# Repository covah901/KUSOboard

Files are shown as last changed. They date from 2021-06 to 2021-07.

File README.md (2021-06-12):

# KUSOboard
KUSOboard is a Longan Nano based keyboard using KarlK90's branch of QMK 
All info on Karl's branch and YAEMK can be found here: https://karlk90.github.io/yaemk-split-kb/

Regarding the naming of the files, I had started out meaning to make an Atreus size board, but decided against it shortly after starting the project. 
It was reduced to something more like a Reviung39. 

album: https://imgur.com/a/PWmJwKW

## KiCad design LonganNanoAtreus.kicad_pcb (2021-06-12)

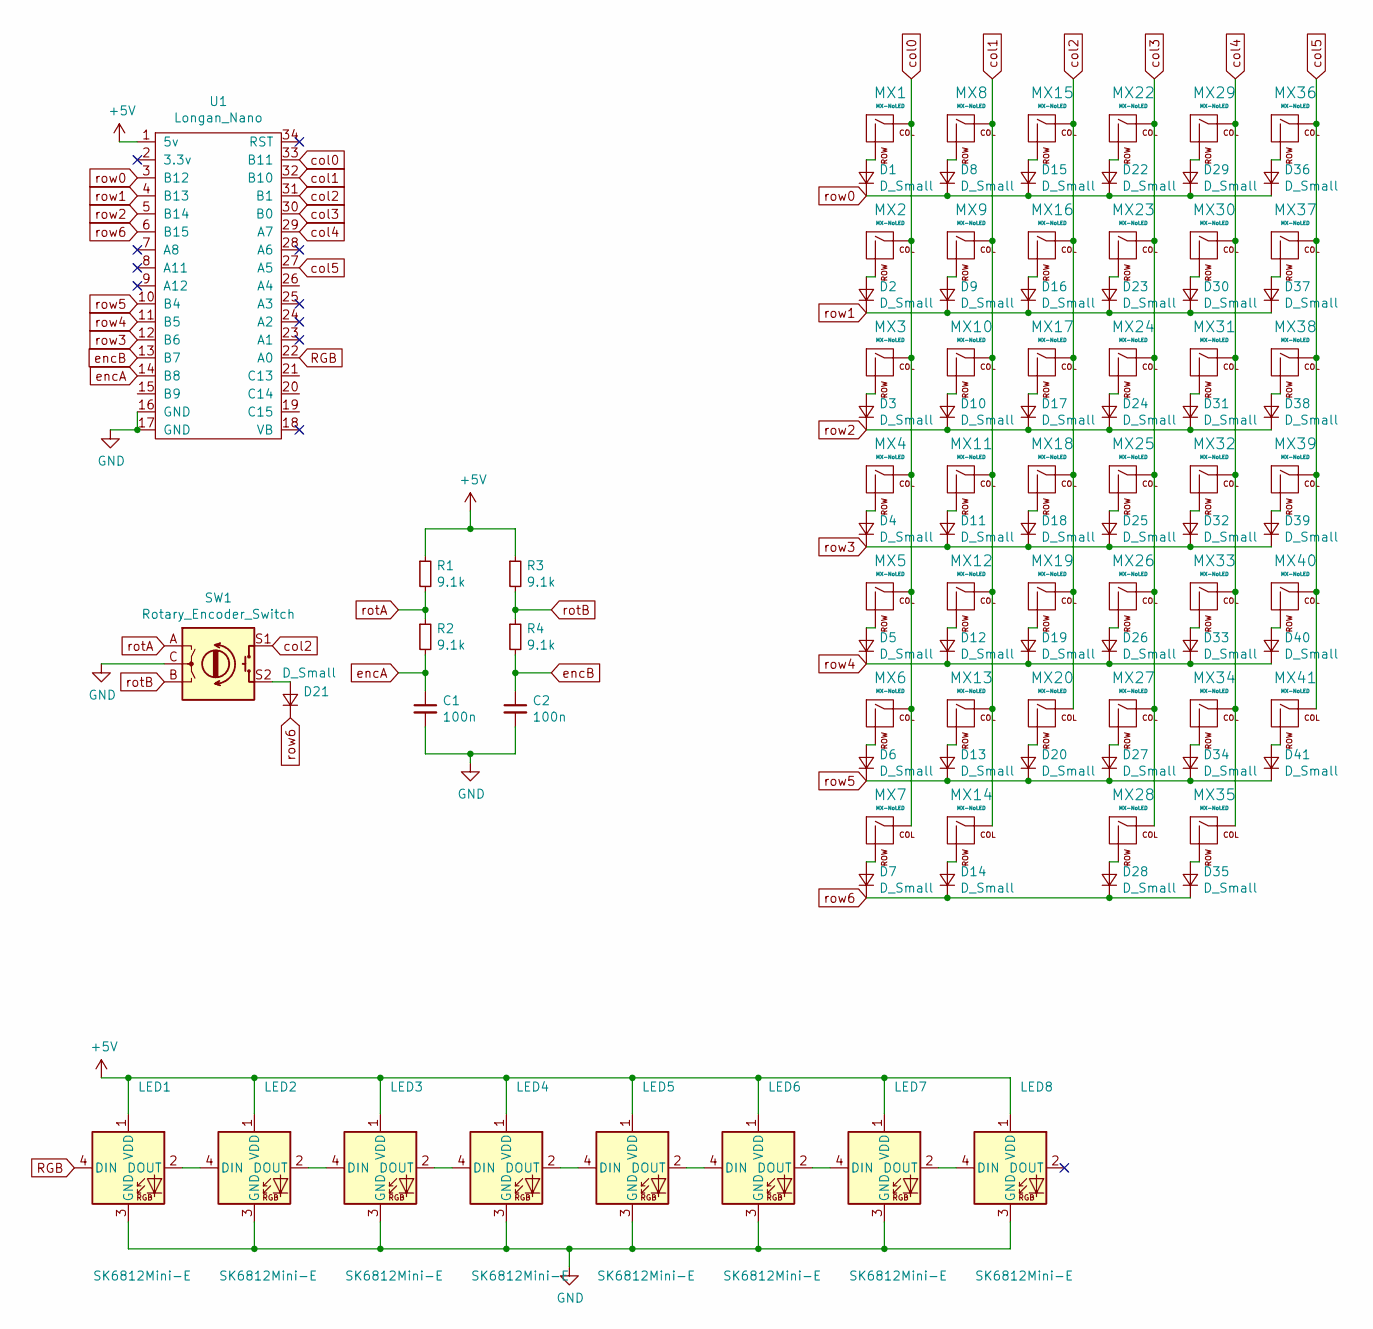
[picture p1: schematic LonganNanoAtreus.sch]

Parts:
C1, C2: 100n; C_0805_2012Metric_Pad1.15x1.40mm_HandSolder
D1, D2, D3, D4, D5, D6, D7, D8, D9, D10, D11, D12, D13, D14, D15, D16, D17, D18, D19, D20, D21, D22, D23, D24, D25, D26, D27, D28, D29, D30, D31, D32, D33, D34, D35, D36, D37, D38, D39, D40, D41: D_Small; D_SOD-123F
LED1, LED2, LED3, LED4, LED5, LED6, LED7, LED8: SK6812Mini-E; SK6812-MINI-E
MX1, MX2, MX3, MX4, MX5, MX6, MX7, MX8, MX9, MX10, MX11, MX12, MX13, MX14, MX15, MX16, MX17, MX18, MX19, MX20, MX22, MX23, MX24, MX25, MX26, MX27, MX28, MX29, MX30, MX31, MX32, MX33, MX34, MX35, MX36, MX37, MX38, MX39, MX40, MX41: MX-NoLED; MXOnly-1U-NoLED
R1, R2, R3, R4: 9.1k; R_0805_2012Metric_Pad1.15x1.40mm_HandSolder
SW1: Rotary_Encoder_Switch; EVQWGD001
U1: Longan_Nano

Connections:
+5V: LED1.1 (VDD), LED2.1 (VDD), LED3.1 (VDD), LED4.1 (VDD), LED5.1 (VDD), LED6.1 (VDD), LED7.1 (VDD), LED8.1 (VDD), R1.1, R3.1, U1.1 (5v)
GND: C1.2, C2.2, LED1.3 (GND), LED2.3 (GND), LED3.3 (GND), LED4.3 (GND), LED5.3 (GND), LED6.3 (GND), LED7.3 (GND), LED8.3 (GND), SW1.C, U1.16 (GND), U1.17 (GND)
unnamed: D1.2 (A), MX1.2 (ROW)
unnamed: D2.2 (A), MX2.2 (ROW)
unnamed: D3.2 (A), MX3.2 (ROW)
unnamed: D4.2 (A), MX4.2 (ROW)
unnamed: D5.2 (A), MX5.2 (ROW)
unnamed: D6.2 (A), MX6.2 (ROW)
unnamed: D7.2 (A), MX7.2 (ROW)
unnamed: D8.2 (A), MX8.2 (ROW)
unnamed: D9.2 (A), MX9.2 (ROW)
unnamed: D10.2 (A), MX10.2 (ROW)
unnamed: D11.2 (A), MX11.2 (ROW)
unnamed: D12.2 (A), MX12.2 (ROW)
unnamed: D13.2 (A), MX13.2 (ROW)
unnamed: D14.2 (A), MX14.2 (ROW)
unnamed: D15.2 (A), MX15.2 (ROW)
unnamed: D16.2 (A), MX16.2 (ROW)
unnamed: D17.2 (A), MX17.2 (ROW)
unnamed: D18.2 (A), MX18.2 (ROW)
unnamed: D19.2 (A), MX19.2 (ROW)
unnamed: D20.2 (A), MX20.2 (ROW)
unnamed: D21.2 (A), SW1.S2
unnamed: D22.2 (A), MX22.2 (ROW)
unnamed: D23.2 (A), MX23.2 (ROW)
unnamed: D24.2 (A), MX24.2 (ROW)
unnamed: D25.2 (A), MX25.2 (ROW)
unnamed: D26.2 (A), MX26.2 (ROW)
unnamed: D27.2 (A), MX27.2 (ROW)
unnamed: D28.2 (A), MX28.2 (ROW)
unnamed: D29.2 (A), MX29.2 (ROW)
unnamed: D30.2 (A), MX30.2 (ROW)
unnamed: D31.2 (A), MX31.2 (ROW)
unnamed: D32.2 (A), MX32.2 (ROW)
unnamed: D33.2 (A), MX33.2 (ROW)
unnamed: D34.2 (A), MX34.2 (ROW)
unnamed: D35.2 (A), MX35.2 (ROW)
unnamed: D36.2 (A), MX36.2 (ROW)
unnamed: D37.2 (A), MX37.2 (ROW)
unnamed: D38.2 (A), MX38.2 (ROW)
unnamed: D39.2 (A), MX39.2 (ROW)
unnamed: D40.2 (A), MX40.2 (ROW)
unnamed: D41.2 (A), MX41.2 (ROW)
unnamed: LED1.2 (DOUT), LED2.4 (DIN)
unnamed: LED2.2 (DOUT), LED3.4 (DIN)
unnamed: LED3.2 (DOUT), LED4.4 (DIN)
unnamed: LED4.2 (DOUT), LED5.4 (DIN)
unnamed: LED5.2 (DOUT), LED6.4 (DIN)
unnamed: LED6.2 (DOUT), LED7.4 (DIN)
unnamed: LED7.2 (DOUT), LED8.4 (DIN)
RGB: LED1.4 (DIN), U1.22 (A0)
col0: MX1.1 (COL), MX2.1 (COL), MX3.1 (COL), MX4.1 (COL), MX5.1 (COL), MX6.1 (COL), MX7.1 (COL), U1.33 (B11)
col1: MX8.1 (COL), MX9.1 (COL), MX10.1 (COL), MX11.1 (COL), MX12.1 (COL), MX13.1 (COL), MX14.1 (COL), U1.32 (B10)
col2: MX15.1 (COL), MX16.1 (COL), MX17.1 (COL), MX18.1 (COL), MX19.1 (COL), MX20.1 (COL), SW1.S1, U1.31 (B1)
col3: MX22.1 (COL), MX23.1 (COL), MX24.1 (COL), MX25.1 (COL), MX26.1 (COL), MX27.1 (COL), MX28.1 (COL), U1.30 (B0)
col4: MX29.1 (COL), MX30.1 (COL), MX31.1 (COL), MX32.1 (COL), MX33.1 (COL), MX34.1 (COL), MX35.1 (COL), U1.29 (A7)
col5: MX36.1 (COL), MX37.1 (COL), MX38.1 (COL), MX39.1 (COL), MX40.1 (COL), MX41.1 (COL), U1.27 (A5)
encA: C1.1, R2.2, U1.14 (B8)
encB: C2.1, R4.2, U1.13 (B7)
rotA: R1.2, R2.1, SW1.A
rotB: R3.2, R4.1, SW1.B
row0: D1.1 (K), D8.1 (K), D15.1 (K), D22.1 (K), D29.1 (K), D36.1 (K), U1.3 (B12)
row1: D2.1 (K), D9.1 (K), D16.1 (K), D23.1 (K), D30.1 (K), D37.1 (K), U1.4 (B13)
row2: D3.1 (K), D10.1 (K), D17.1 (K), D24.1 (K), D31.1 (K), D38.1 (K), U1.5 (B14)
row3: D4.1 (K), D11.1 (K), D18.1 (K), D25.1 (K), D32.1 (K), D39.1 (K), U1.12 (B6)
row4: D5.1 (K), D12.1 (K), D19.1 (K), D26.1 (K), D33.1 (K), D40.1 (K), U1.11 (B5)
row5: D6.1 (K), D13.1 (K), D20.1 (K), D27.1 (K), D34.1 (K), D41.1 (K), U1.10 (B4)
row6: D7.1 (K), D14.1 (K), D21.1 (K), D28.1 (K), D35.1 (K), U1.6 (B15)

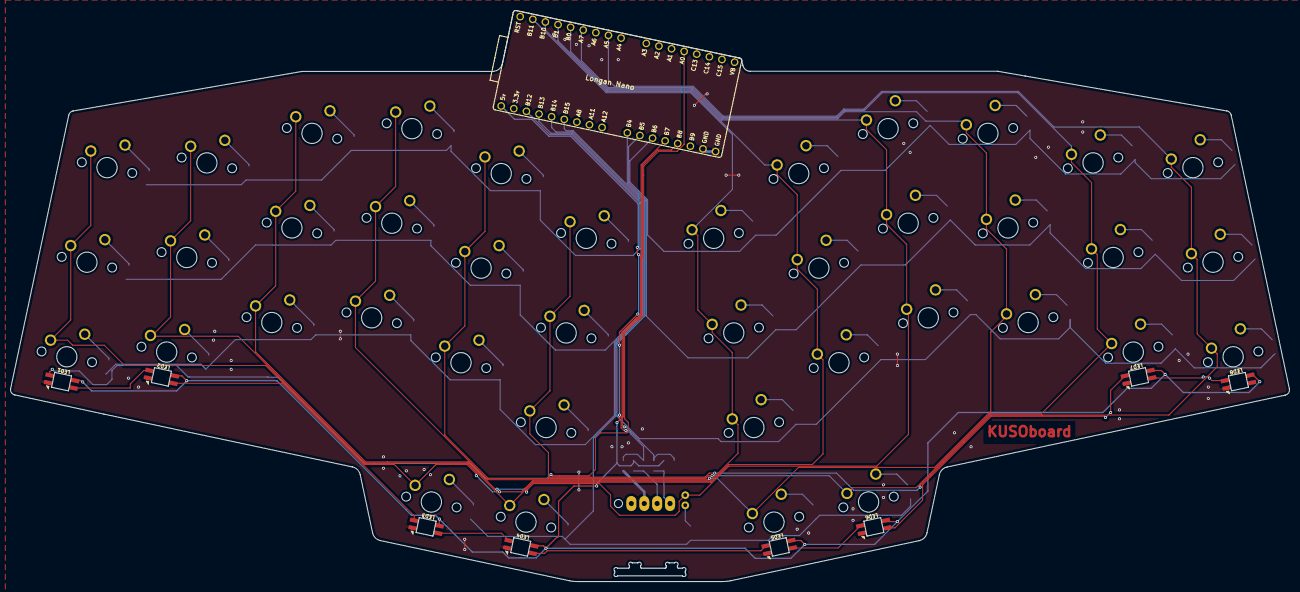
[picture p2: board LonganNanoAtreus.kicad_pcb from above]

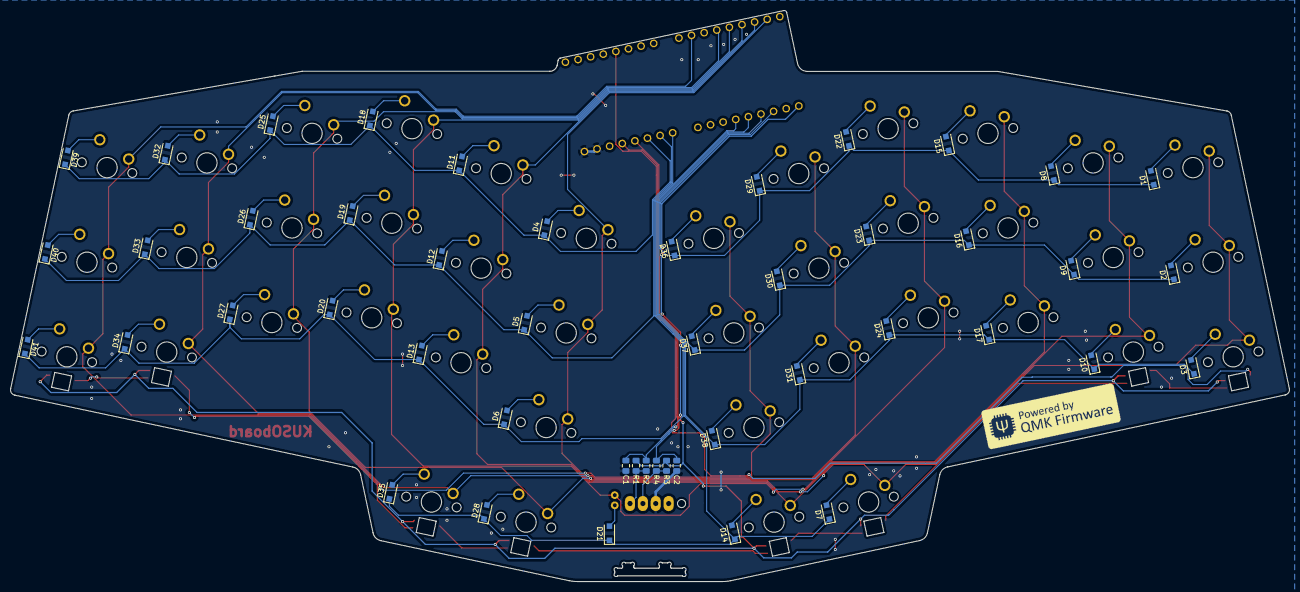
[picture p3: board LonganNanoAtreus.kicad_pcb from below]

Board: 2 copper layers, 252.0 x 112.5 mm, 97 parts (47 on the bottom side), 68 nets.

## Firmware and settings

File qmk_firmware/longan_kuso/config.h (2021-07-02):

#pragma once

#include "config_common.h"

/* USB CONFIG */
#define USB_POLLING_INTERVAL_MS 1
#define FORCE_NKRO
/* Device descriptor parameters */
#define VENDOR_ID 0x4B4B   // KK
#define PRODUCT_ID 0x5941  // YA
#define DEVICE_VER 0x0003
#define MANUFACTURER KARLK90

// clang-format off
#define PRODUCT QMK LONGAN NANO TEMPLATE
#define DESCRIPTION LONGAN NANO
// clang-format on

/* MATRIX CONFIG */
#define MATRIX_ROWS 7
#define MATRIX_COLS 6
#define MATRIX_COL_PINS \
    { B11, B10, B1, B0, A7, A5 }
#define MATRIX_ROW_PINS \
    { B12, B13, B14, B6, B5, B4, B15 }
#define DIODE_DIRECTION COL2ROW

#define DEBUG_MATRIX_SCAN_RATE
#define DEBOUNCE 5
#define BUSY_WAIT
#define BUSY_WAIT_INSTRUCTIONS 500
#define GPIO_INPUT_PIN_DELAY 8

#define QMK_KEYS_PER_SCAN 8

/* ROTARY ENCODER*/
#define ENCODERS_PAD_A { B7 }
#define ENCODERS_PAD_B { B8 }
#define ENCODER_RESOLUTION 4

/* WS2812 DRIVER */
#define GD32_DMA_REQUIRED
#define RGBLED_NUM 8
#define DRIVER_LED_TOTAL RGBLED_NUM
#define FASTLED_SCALE8_FIXED 1
#define RGBLIGHT_LIMIT_VAL 50
#define RGBLIGHT_ANIMATIONS

/* Option 1 */
#define RGB_DI_PIN A0
#define WS2812_PWM_DRIVER PWMD2
#define WS2812_PWM_CHANNEL 1
#define WS2812_DMA_CHANNEL 2
#define WS2812_DMA_STREAM GD32_DMA0_STREAM1

/* Option 2 */
// Change GD32_PWM_USE_TIM0 to TRUE and GD32_PWM_USE_TIM1 to FALSE
// in mcuconf.h if you want this configuration.
// #define WS2812_PWM_DRIVER PWMD1
// #define WS2812_PWM_CHANNEL 3
// #define WS2812_PWM_PAL_MODE 6
// #define WS2812_DMA_CHANNEL 5
// #define WS2812_DMA_STREAM GD32_DMA0_STREAM4
// #define RGB_DI_PIN A10


/* TAPPING CONFIG */
#define TAPPING_TERM 500
#define TAPPING_TOGGLE 2
#define TAPPING_FORCE_HOLD
#define IGNORE_MOD_TAP_INTERRUPT
#define PERMISSIVE_HOLD_PER_KEY

/* MOUSEKEY CONFIG */
#undef MOUSEKEY_DELAY
#define MOUSEKEY_DELAY 0
#undef MOUSEKEY_INTERVAL
#define MOUSEKEY_INTERVAL 16
#undef MOUSEKEY_WHEEL_DELAY
#define MOUSEKEY_WHEEL_DELAY 0
#undef MOUSEKEY_MAX_SPEED
#define MOUSEKEY_MAX_SPEED 6
#undef MOUSEKEY_TIME_TO_MAX
#define MOUSEKEY_TIME_TO_MAX 64

/* JOYSTICK CONFIG */
#define JOYSTICK_AXES_COUNT 0
#define JOYSTICK_BUTTON_COUNT 0

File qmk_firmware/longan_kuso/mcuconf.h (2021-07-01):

/*
    ChibiOS - Copyright (C) 2006..2018 Giovanni Di Sirio
    ChibiOS - Copyright (C) 2021 Stefan Kerkmann

    Licensed under the Apache License, Version 2.0 (the "License");
    you may not use this file except in compliance with the License.
    You may obtain a copy of the License at

        http://www.apache.org/licenses/LICENSE-2.0

    Unless required by applicable law or agreed to in writing, software
    distributed under the License is distributed on an "AS IS" BASIS,
    WITHOUT WARRANTIES OR CONDITIONS OF ANY KIND, either express or implied.
    See the License for the specific language governing permissions and
    limitations under the License.
*/

#pragma once

#define GD32VF103_MCUCONF
#define GD32VF103CB

/*
 * GD32VF103 drivers configuration.
 * The following settings override the default settings present in
 * the various device driver implementation headers.
 * Note that the settings for each driver only have effect if the whole
 * driver is enabled in halconf.h.
 *
 * IRQ priorities:
 * 0...15       Lowest...Highest.
 *
 * DMA priorities:
 * 0...3        Lowest...Highest.
 */

/*
 * HAL driver system settings.
*/

#if defined(OVERCLOCK_120MHZ)
// (8MHz / 2) * 30 = 120MHz Sysclock
#define GD32_ALLOW_120MHZ_SYSCLK
#define GD32_PLLMF_VALUE                   30
#define GD32_USBFSPSC                      GD32_USBFSPSC_DIV2P5
#else
// (8MHz / 2) * 24 = 96MHz Sysclock
#define GD32_PLLMF_VALUE                   24
#define GD32_USBFSPSC                      GD32_USBFSPSC_DIV2
#endif

#define GD32_NO_INIT                       FALSE
#define GD32_IRC8M_ENABLED                 TRUE
#define GD32_IRC40K_ENABLED                FALSE
#define GD32_HXTAL_ENABLED                 TRUE
#define GD32_LXTAL_ENABLED                 FALSE
#define GD32_SCS                           GD32_SCS_PLL
#define GD32_PLLSEL                        GD32_PLLSEL_PREDV0
#define GD32_PREDV0SEL                     GD32_PREDV0SEL_HXTAL
#define GD32_PREDV0_VALUE                  2
#define GD32_PREDV1_VALUE                  2
#define GD32_PLL1MF_VALUE                  14
#define GD32_PLL2MF_VALUE                  13
#define GD32_AHBPSC                        GD32_AHBPSC_DIV1
#define GD32_APB1PSC                       GD32_APB1PSC_DIV2
#define GD32_APB2PSC                       GD32_APB2PSC_DIV1
#define GD32_ADCPSC                        GD32_ADCPSC_DIV16
#define GD32_USB_CLOCK_REQUIRED            TRUE
#define GD32_I2S_CLOCK_REQUIRED            FALSE
#define GD32_CKOUT0SEL                     GD32_CKOUT0SEL_NOCLOCK
#define GD32_RTCSRC                        GD32_RTCSRC_NOCLOCK
#define GD32_PVD_ENABLE                    FALSE
#define GD32_LVDT                          GD32_LVDT_LEV0

/*
 * ECLIC system settings.
 */
#define ECLIC_TRIGGER_DEFAULT              ECLIC_POSTIVE_EDGE_TRIGGER
#define ECLIC_DMA_TRIGGER                  ECLIC_TRIGGER_DEFAULT

/*
 * IRQ system settings.
 */
#define GD32_IRQ_EXTI0_PRIORITY            6
#define GD32_IRQ_EXTI1_PRIORITY            6
#define GD32_IRQ_EXTI2_PRIORITY            6
#define GD32_IRQ_EXTI3_PRIORITY            6
#define GD32_IRQ_EXTI4_PRIORITY            6
#define GD32_IRQ_EXTI5_9_PRIORITY          6
#define GD32_IRQ_EXTI10_15_PRIORITY        6
#define GD32_IRQ_EXTI0_TRIGGER             ECLIC_TRIGGER_DEFAULT
#define GD32_IRQ_EXTI1_TRIGGER             ECLIC_TRIGGER_DEFAULT
#define GD32_IRQ_EXTI2_TRIGGER             ECLIC_TRIGGER_DEFAULT
#define GD32_IRQ_EXTI3_TRIGGER             ECLIC_TRIGGER_DEFAULT
#define GD32_IRQ_EXTI4_TRIGGER             ECLIC_TRIGGER_DEFAULT
#define GD32_IRQ_EXTI5_9_TRIGGER           ECLIC_TRIGGER_DEFAULT
#define GD32_IRQ_EXTI10_15_TRIGGER         ECLIC_TRIGGER_DEFAULT

/*
 * ADC driver system settings.
 */
#define GD32_ADC_USE_ADC0                  FALSE
#define GD32_ADC_ADC0_DMA_PRIORITY         2
#define GD32_ADC_ADC0_IRQ_PRIORITY         6

/*
 * CAN driver system settings.
 */
#define GD32_CAN_USE_CAN0                  FALSE
#define GD32_CAN_CAN0_IRQ_PRIORITY         11
#define GD32_CAN_USE_CAN1                  FALSE
#define GD32_CAN_CAN1_IRQ_PRIORITY         11
#define GD32_CAN_CAN0_IRQ_TRIGGER          ECLIC_TRIGGER_DEFAULT
#define GD32_CAN_CAN1_IRQ_TRIGGER          ECLIC_TRIGGER_DEFAULT

/*
 * CRC driver system settings.
 */
#define GD32_CRC_USE_CRC0                   FALSE
#define GD32_CRC_CRC0_DMA_IRQ_PRIORITY      14
#define GD32_CRC_CRC0_DMA_PRIORITY          2
#define GD32_CRC_CRC0_DMA_STREAM            GD32_DMA_STREAM_ID(0, 0)
#define CRC_USE_DMA                         FALSE
#define CRCSW_USE_CRC1                      FALSE
#define CRCSW_CRC32_TABLE                   TRUE
#define CRCSW_CRC16_TABLE                   TRUE
#define CRCSW_PROGRAMMABLE                  TRUE

/*
 * DAC driver system settings.
 */
#define GD32_DAC_USE_DAC_CH1              FALSE
#define GD32_DAC_USE_DAC_CH2              FALSE

/*
 * GPT driver system settings.
 */
#define GD32_GPT_USE_TIM0                  FALSE
#define GD32_GPT_USE_TIM1                  FALSE
#define GD32_GPT_USE_TIM2                  FALSE
#define GD32_GPT_USE_TIM3                  FALSE
#define GD32_GPT_USE_TIM4                  FALSE
#define GD32_GPT_TIM0_IRQ_PRIORITY         7
#define GD32_GPT_TIM1_IRQ_PRIORITY         7
#define GD32_GPT_TIM2_IRQ_PRIORITY         7
#define GD32_GPT_TIM3_IRQ_PRIORITY         7
#define GD32_GPT_TIM4_IRQ_PRIORITY         7
#define GD32_GPT_TIM0_IRQ_TRIGGER          ECLIC_TRIGGER_DEFAULT
#define GD32_GPT_TIM1_IRQ_TRIGGER          ECLIC_TRIGGER_DEFAULT
#define GD32_GPT_TIM2_IRQ_TRIGGER          ECLIC_TRIGGER_DEFAULT
#define GD32_GPT_TIM3_IRQ_TRIGGER          ECLIC_TRIGGER_DEFAULT
#define GD32_GPT_TIM4_IRQ_TRIGGER          ECLIC_TRIGGER_DEFAULT
#define GD32_GPT_TIM5_IRQ_TRIGGER          ECLIC_TRIGGER_DEFAULT
#define GD32_GPT_TIM6_IRQ_TRIGGER          ECLIC_TRIGGER_DEFAULT

/*
 * I2S driver system settings.
 */
#define GD32_I2S_USE_SPI1                  FALSE
#define GD32_I2S_USE_SPI2                  FALSE
#define GD32_I2S_SPI1_IRQ_PRIORITY         10
#define GD32_I2S_SPI2_IRQ_PRIORITY         10
#define GD32_I2S_SPI1_DMA_PRIORITY         1
#define GD32_I2S_SPI2_DMA_PRIORITY         1
#define GD32_I2S_DMA_ERROR_HOOK(i2sp)      osalSysHalt("DMA failure")

/*
 * I2C driver system settings.
 */
#define GD32_I2C_USE_I2C0                  FALSE
#define GD32_I2C_USE_I2C1                  FALSE
#define GD32_I2C_BUSY_TIMEOUT              50
#define GD32_I2C_I2C0_IRQ_PRIORITY         10
#define GD32_I2C_I2C1_IRQ_PRIORITY         5
#define GD32_I2C_I2C0_IRQ_TRIGGER          ECLIC_TRIGGER_DEFAULT
#define GD32_I2C_I2C1_IRQ_TRIGGER          ECLIC_TRIGGER_DEFAULT
#define GD32_I2C_I2C0_DMA_PRIORITY         2
#define GD32_I2C_I2C1_DMA_PRIORITY         2
#define GD32_I2C_DMA_ERROR_HOOK(i2cp)      osalSysHalt("DMA failure")
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
